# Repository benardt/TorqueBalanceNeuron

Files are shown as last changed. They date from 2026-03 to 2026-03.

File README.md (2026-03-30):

# Torque Balance Neuron
Use the lever balance to simulate the functioning and learning of a [artificial neuron](https://en.wikipedia.org/wiki/Artificial_neuron) (in the sense of artificial intelligence).

## Mechanical device
The instrument is a mechanical deflection-mode torque-balance letter scale comprising a cylindrical drum, a rigid lever arm, an adjustable counterweight, and a suspended plate driven by a rope. The scale measures mass by rotating to an equilibrium angle between 0° and 90°, defined by the balance of gravitational moments and rope tension. The design assumes idealized, negligible friction in bearings and rope contact.

<p align="center">
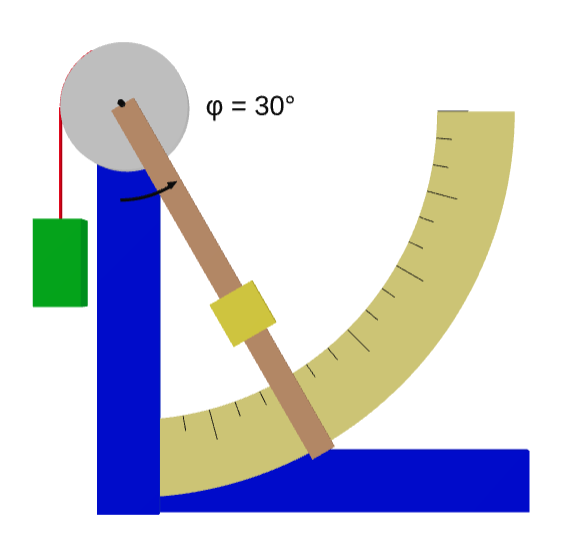
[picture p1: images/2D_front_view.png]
  
</p>

STL (ascii) 3D file [here](src/playground.stl)

## Nomenclature

| Repère | Quantité | Nom | Matière | Dimension |
|---|---|-----|---|---|
| A | 1 | Base 1 | Bois | L=120mm (9x38) |
| B | 1 | Base 2 | Bois | L=220mm (9x38) |
| C | 1 | Support vertical | Bois | L=300mm (9x38) |
| D | 1 | Cadran gradué | Contreplaqué | (ép: 3mm) |
| E | 1 | Tambour | Contreplaqué | R=75mm (ép: 12mm) |
| F | 1 | Corde | Synthétique | L=200mm |
| G | 1 | Crochet | Laiton | |
| H | 1 | Roulement à bille 608 | Acier | |
| I | 1 | Vis M8 | Acier | M8x40mm |
| J | 2 | Écrou M8 | Acier | |
| K | 1 | Levier | Bois | | L=250mm l=34mm (ép: 5mm) |
| L | 1 | Vis M6 (contrepoids) | Acier | M6x40mm |
| M | 1 | Écrou M6 (contrepoids) | Acier | |

## PoC View
<p align="center">
  
  
  
  
</p>

## Évaluation pilote

L'évaluation pilote permet de valider trois fonctions essentielles. Elle permet : 
* de valider la faisabilité du dispositif en conditions réelles
* d'identifier les points de fragilité pédagogique qui orienteront les améliorations du protocole
* de fournir une preuve de concept suffisante pour justifier une étude plus large et plus rigoureuse

Date : samedi 24 janvier 2026
Lieu : Orléans - Groupe scolaire Sainte Croix - Saint Euverte //
Lors de la journée des métiers organisée par l'APEL pour des élèves des classes de 4e et 3e du collège (cycle 4). L'évaluation faisait partie d'un atelier sur l'intelligence articielle.

3 groupes dans la matinée et 3 groupes dans l'après-midi.

## QCM pour l'évaluation

QCM (Questionnaire à Choix Multiple). Voir chapitre Ressources

## Ressources

* [Grille](src/GrilleProcedure.txt) pour chaque époque du SDGD
* [QCM](src/QCM_Neurone_Mecanique.pdf) avec correction
* [Vidéo](https://photos.app.goo.gl/NeYP4QzwnGSr2SjAA)

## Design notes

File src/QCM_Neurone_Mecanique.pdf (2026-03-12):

# QCM — Le Neurone Mécanique

Objectifs pédagogiques mesurables — Fondements de l'Intelligence Artificielle
Nom : ________________________________ Classe : ___________ Date : ___________

## Présentation du QCM

Ce questionnaire évalue la compréhension des six notions fondamentales du neurone artificiel à travers le dispositif mécanique de la balance à levier. Chaque question comporte une seule réponse correcte.

Thèmes évalués :

Entrée (Q1–Q2) | Poids synaptique (Q3–Q4) | Sortie (Q5–Q6)
Erreur (Q7–Q8) | Descente de gradient (Q9–Q10) | Convergence (Q11–Q12)

## Questions

Pour chaque question, cochez la lettre correspondant à la seule bonne réponse. La réponse correcte est indiquée par ✓ dans la version corrigée.

### Notion d'entrée

Q1 | [Entrée] Dans le dispositif de la balance à levier, qu'est-ce qui joue le rôle de l'entrée du neurone ?

A La position rcw du contrepoids sur la glissière
B ✓ La masse minput déposée sur le plateau
C L'angle φ lu sur le cadran gradué
D Le rayon R du tambour cylindrique

Objectif pédagogique : L'élève est capable d'identifier le composant physique correspondant à l'entrée (signal) d'un neurone artificiel.

Q2 | [Entrée] Dans un neurone artificiel, l'entrée x correspond à une information brute fournie au système. Quel énoncé décrit le mieux son rôle ?

A Elle détermine le critère d'arrêt de l'apprentissage
B Elle fixe la non-linéarité de la fonction d'activation
C ✓ Elle est multipliée par le poids synaptique pour produire un signal pondéré
D Elle mesure l'écart entre la prédiction et la valeur cible

Objectif pédagogique : L'élève est capable de décrire le rôle fonctionnel de l'entrée dans le calcul effectué par un neurone.

### Notion de poids synaptique

Q3 | [Poids synaptique] Quel composant de la balance à levier correspond au poids synaptique w d'un neurone artificiel ?

A Le rayon R du tambour
B La masse minput déposée sur le plateau
C ✓ La position radiale rcw du contrepoids

D L'angle d'équilibre φeq affiché sur le cadran

Objectif pédagogique : L'élève est capable d'identifier l'analogie mécanique du poids synaptique et de comprendre que c'est le paramètre ajustable du système.

Q4 | [Poids synaptique] Que se passe-t-il mécaniquement si on éloigne le contrepoids du pivot (rcw augmente) ?
A ✓ Le couple résistant augmente, donc l'angle d'équilibre φ diminue pour une même | entrée

B Le couple moteur augmente, donc l'angle d'équilibre φ augmente
C La sensibilité du système est inchangée
D Le système sature immédiatement à 90°

Objectif pédagogique : L'élève est capable d'expliquer l'effet d'une modification du poids synaptique sur la sortie du neurone.

### Notion de sortie

Q5 | [Sortie] Dans le neurone mécanique, quelle grandeur constitue la sortie du système ?

A La masse totale déposée sur le plateau
B La position du contrepoids rcw après apprentissage
C ✓ L'angle d'équilibre φeq lu sur le cadran gradué
D La force de tension exercée sur la corde

Objectif pédagogique : L'élève est capable d'identifier la sortie du neurone mécanique et de la relier à la notion de prédiction dans un modèle d'IA.

### Notion d'erreur

Q7 | [Erreur] Dans la procédure d'apprentissage manuel, l'erreur signée ei pour un exemple i est définie comme :

A ei = ti − φi (cible moins mesure)
B ✓ ei = φi − ti (mesure moins cible)
C ei = |φi × ti|
D ei = rcw / ti

Objectif pédagogique : L'élève est capable de calculer l'erreur de prédiction d'un neurone pour un exemple donné.

Q8 | [Erreur] L'erreur absolue moyenne (MAE) sur 5 exemples vaut 18°. Que doit faire l'élève selon la règle de taille de pas ?

A Déplacer le contrepoids de 2 mm
B ✓ Déplacer le contrepoids de 5 mm
C Déplacer le contrepoids de 10 mm
D Ne pas modifier rcw car la MAE est acceptable

Objectif pédagogique : L'élève est capable d'utiliser la MAE comme indicateur pour choisir la taille du pas d'ajustement.

### Notion de descente de gradient

Q9 | [Descente de gradient] L'erreur moyenne signée ē est négative (ē < 0). Cela signifie que le système sous-prédit l'angle cible. Que doit-on faire ?

A Augmenter rcw (déplacer le contrepoids vers l'extérieur)
B ✓ Diminuer rcw (rapprocher le contrepoids du pivot)
C Garder rcw inchangé et attendre la prochaine époque
D Remplacer la masse minput par une plus grande

Objectif pédagogique : L'élève est capable d'appliquer la règle de signe de la descente de gradient pour corriger la direction du paramètre.

Q10 | [Descente de gradient] Pourquoi déplace-t-on le contrepoids par petits pas successifs plutôt qu'en un seul grand déplacement ?

A Pour éviter d'endommager mécaniquement le dispositif
B ✓ Parce qu’un grand pas risque de dépasser la solution optimale (overshoot)
C Parce que la règle impose toujours un pas de 2 mm
D Pour respecter le nombre maximum de 3 époques

Objectif pédagogique : L'élève est capable d'expliquer pourquoi un pas d'apprentissage trop grand peut nuire à la convergence.

### Notion de convergence

Q11 | [Convergence] Quel critère indique que l'apprentissage a convergé dans la procédure manuelle ?

A Le contrepoids est positionné à l'extrémité de la glissière
B ✓ La MAE est inférieure ou égale à 2° de façon stable sur plusieurs époques
C L'erreur moyenne signée ē est exactement égale à zéro sur une seule époque
D Le nombre d'époques atteint 10

Objectif pédagogique : L'élève est capable d'énoncer un critère d'arrêt opérationnel de l'apprentissage basé sur la MAE.

Q12 | [Convergence] Lors de l'expérimentation en classe, qu'est-ce qui risque de compromettre la convergence si le pas choisi est trop grand ?

A Le levier se bloque mécaniquement à 0°
B ✓ Le système oscille autour de la solution sans jamais se stabiliser
C La MAE augmente de façon monotone à chaque époque
D Les élèves ne peuvent plus lire le cadran gradué

Objectif pédagogique : L'élève est capable d'identifier le phénomène d'oscillation comme symptôme d'un taux d'apprentissage trop élevé.

## Grille de score

entrée | poids synaptique | sortie | erreur | descente de gradient | convergence
__ / 2 | __ / 2 | __ / 1 | __ / 2 | __ / 2 | __ / 2

### TOTAL : _____ / 11

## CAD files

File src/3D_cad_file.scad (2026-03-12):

// Simplified - correct physics, clean visualization
drum_radius = 40;
drum_height = 16;
lever_length = 250;
rope_diam = 1;
phi = 30;

// Fixed rope exit point (left side of drum)
exit_x = -drum_radius;

// Rope unwound length
rope_unwound = 50 + drum_radius * ((phi) * 3.14159 / 180);

// Main support
support_length = 280;
support_w = 40;
support_d = 9;
offset_z = 20;
color("Blue") {
translate([0, -(support_length/2-20), -offset_z])
cube([support_w, support_length, support_d], center = true);

translate([-support_w/2,-support_length+20,-offset_z-3*support_d/2])
cube([support_length,support_w,support_d]);
}

// cadran pour afficher les graduations d'angles

// Paramètres
r_int = 200;
r_ext = 250;
epaisseur = 3;
angle = 90;   // quart de cadran
$fn = 200;

translate([0, 0, -offset_z-support_d/2])
rotate([0, 0, -90])
linear_extrude(height = epaisseur)
    intersection() {
        // Anneau (cadran)
        difference() {
            circle(r = r_ext);
            circle(r = r_int);
        }

        // Secteur angulaire 90°
        polygon(points=[
            [0,0],
            [2*r_ext*cos(angle),  2*r_ext*sin(angle)],
            [2*r_ext*cos(0),      2*r_ext*sin(0)]
            
        ]);
    }


module ticks_cadran(r_int, r_ext, angle=90, pas=5, pas_long=15, ep=3, h=1.2) {
    // h = hauteur (épaisseur) des ticks en extrusion Z
    // ep = hauteur du cadran (pour synchroniser si besoin)
    linear_extrude(height = h)
    for (a = [0:pas:angle]) {
        is_long = (a % pas_long == 0);
        len = is_long ? 20 : 10;
        // On place un petit rectangle radial au bon angle
        rotate(a)
            translate([r_int, 0, 0])
                square([len, h], center = false); // longueur radiale × épaisseur 2D
    }
}

// Exemple d’appel, avec même placement/rotation que le cadran
translate([0, 0, -offset_z - support_d/2 + epaisseur])
rotate([0, 0, -90])
color("black")
ticks_cadran(r_int, r_ext, angle=90, pas=5, pas_long=15, ep=epaisseur, h=0.5);



// Pivot shaft (through drum center)
color("Black")
cylinder(h = 50, r = 2, center = true);

// Drum and lever (rotate together)
module drum_lever () {
    rotate([0, 0, -(90-phi)]) {
        // Drum
        color("Silver")
        cylinder(h = drum_height, r = drum_radius, center = true);
        
        // Lever
        color("Sienna")
        translate([lever_length/2, 0, (drum_height+9)/2])
        cube([lever_length, 16, 9], center = true);
        
        // Counterweight
        translate([150, 0, 10])
        color("Gold")
        cube([30, 30, 30], center = true);
    }
}
drum_lever();

// Rope (vertical from fixed exit point)
color("Red") {
translate([exit_x-rope_diam, 0, 0])
rotate([90, 0, 0])
cylinder(h = rope_unwound, r = rope_diam);

rotate([0, 0, 180-(90-phi)])
translate([rope_diam, 0, 0])
rotate_extrude(angle = (90-phi), convexity = 10)
translate([drum_radius, 0, 0])
circle(r = rope_diam);
}

// Plate
color("Green") {
plate_h = 55;
translate([exit_x-rope_diam, -(plate_h/2)-rope_unwound, 0])
rotate([90, 0, 0])
cube([30, 30, plate_h], center = true);
}

module annotate_phi(phi_deg, radius=60, thickness=1.8, z=drum_height + 20, txt_size=10) {
    // Arc (de 0 à phi_deg) dans le plan XY
    color("Black")
    rotate([0, 0, -90])  // arc de référence à partir de l'axe X positif
    translate([0, 0, z])
    rotate_extrude(angle=phi_deg, convexity=10)
        translate([radius, 0, 0])
            circle(r=thickness/2);

    // Flèche à l'extrémité de l'arc
    // On place un petit triangle au bout de l'arc
    color("Black")
    translate([0, 0, z])
    rotate([0, 0, -90+phi_deg])
    translate([radius+2, 0, 0])  // bout de l'arc
    rotate([0, 0, 90])
        linear_extrude(height=thickness)
            polygon(points=[[0,0],[6,2.5],[0,5]]);  // petite flèche

    // Texte "φ = ...°" (utilise text() -> 2D -> linear_extrude pour 3D)
    // On le place un peu à l'extérieur du rayon pour ne pas chevaucher l'arc
    color("Black")
    translate([0, 0, z + thickness])
    rotate([0, 0, 0])  // orienté à mi-angle
    translate([radius + 20, -txt_size/3, 0])  // décalage radial + léger centrage
        linear_extrude(height=1)
            text(str("φ = ", round(phi_deg), "°"), size=txt_size, halign="center", valign="center");
}

// Affiche l'annotation pour phi
annotate_phi(phi, radius = drum_radius + 20, thickness = 2, z = drum_height + 10, txt_size = 12);
